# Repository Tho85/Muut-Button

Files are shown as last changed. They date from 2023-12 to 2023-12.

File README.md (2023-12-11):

# Muut Button

A hardware button to control the mute state in video conferencing calls.

Muut Button image

## Overview

The device emulates a USB HID Telephony device with buttons and status LEDs. It can be used to mute/unmute and hang up calls in video conferencing software. The built-in LED (or an optional RGB LED ring) visualizes the current mute/unmute/call state. No additional software or browser extensions required.

Successfully tested with Google Meet in Google Chrome. Firefox does not work because it does not implement the WebHID API. Other video conferencing solutions (MS Teams, Skype, ...) might work as well.

## Features

* Mute/unmute video call on button press
* Also works while video call is in background window
* Shows current mute/unmute state via RGB LED ring or builtin LED
* Correctly shows mute state when muted by other participants
* Optional: Push-to-talk
* Optional: Hold to drop call

## Demo

Muut Button demo

## Requirements

### Hardware

* Development board: [ATtiny85 Micro USB Development Board](https://www.aliexpress.com/item/3256805913780170.html)
* Switch: e.g. [CHERRY MX Brown](https://www.cherrymx.de/cherry-mx/mx-original/mx-brown.html)
* RGB LED ring: [Adafruit NeoPixel Ring - 12x](https://www.adafruit.com/product/1643)
* Case + accessories: [3D printed case](hardware/), see [`hardware/`](hardware/) folder

### Software

* See [`firmware/`](firmware/) folder

## Assembly instructions

* See [`hardware/doc/assembly.md`](hardware/doc/assembly.md)

## License

* Firmware: See [`firmware/LICENSE.md`](firmware/LICENSE.md)
* Hardware: See [`hardware/LICENSE.md`](hardware/LICENSE.md)

## Authors

* [Thomas Hollstegge](https://github.com/Tho85)

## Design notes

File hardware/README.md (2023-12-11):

# Muut Button case
[][cc-by-sa]

## Overview

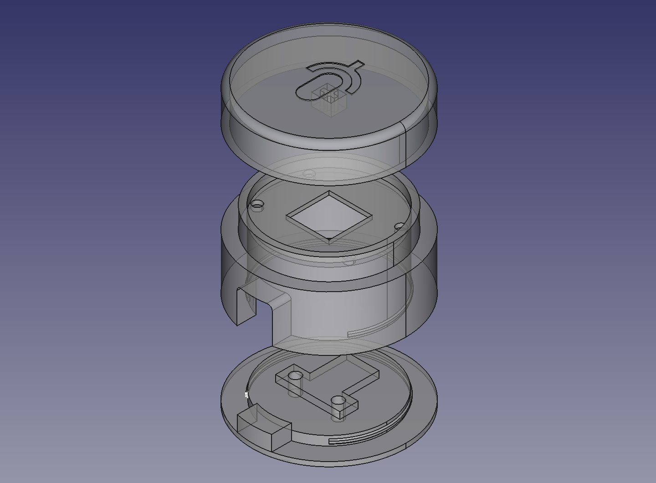
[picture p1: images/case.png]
case image


## Requirements

* Electronics components: See [overall README.md](../README.md)
* A 3D printer and filament
* 2x [M2 threaded inserts](https://turmberg3d.de/products/gewindeeinsatze-fur-kunststoffteile?variant=39376894001347)
* 2x M2x4 screws
* Five short wires (~ 5 cm)
* Some hot glue
* Optional: Foam rubber pad, round

## Assembly instructions

See [doc/assembly.md](doc/assembly.md)

## License

This work is licensed under a
[Creative Commons Attribution-ShareAlike 4.0 International License][cc-by-sa].

[][cc-by-sa]

[cc-by-sa]: http://creativecommons.org/licenses/by-sa/4.0/
[cc-by-sa-image]: https://licensebuttons.net/l/by-sa/4.0/88x31.png
[cc-by-sa-shield]: https://img.shields.io/badge/License-CC%20BY--SA%204.0-lightgrey.svg

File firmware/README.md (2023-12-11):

# Muut Button firmware

A firmware for ATtiny85 microcontrollers that can mute/unmute and hang up calls in video conferencing sofware.

## Features

The firmware emulates the following usages according to the USB HID specification (see [HID Usage Tables](https://usb.org/sites/default/files/hut1_4.pdf)):

| Page name | Page ID | Usage name  | Usage ID |
| --- | --- | --- | --- |
| LED | `0x08`  | Mute | `0x09` |
| LED | `0x08`  | Off-Hook | `0x17` |
| Telephony Device | `0x0B`  | Hook Switch | `0x20` |
| Telephony Device | `0x0B`  | Drop | `0x26` |
| Telephony Device | `0x0B`  | Phone Mute  | `0x2F` |

## Getting Started

### Prerequisites

Hardware:

* Development board: [ATtiny85 Micro USB Development Board](https://www.aliexpress.com/item/3256805913780170.html)
* Or any other ATtiny85 development board where USB communication is handled by the ATtiny85 itself, and not by some additional USB-to-UART controller (CP2102, CH340, etc.)

Software:

* [PlatformIO](https://platform.io)
* [V-USB](https://github.com/obdev/v-usb)

### Installation

* Install [PlatformIO](https://platform.io)
* Clone this repository, `cd firmware/`
* Configure firmware
  * Generate your own config file: `cp include/config.h.example include/config.h`
  * Edit `include/config.h` to suit your needs (see comments there for further description)
* Flash firmware
  * `pio run -t upload`
  * Plug in the device within 60 seconds
* Make sure user has read/write access to the raw USB device:
  * Either drop [`udev rules file`](doc/98-muut.rules) to `/etc/udev/rules.d/`, issue a `sudo udevadm control --reload-rules` and re-plug device (recommended)
  * Or try manually: `sudo chmod 0666 /dev/hidrawX`

### Usage

* Attach device via USB
* Configure video conferencing software to use the device for call controls:
  * [Google Meet](https://support.google.com/meet/answer/12562325?hl=en)

### Advanced usage

If your development board does not already come pre-flashed with it, I highly recommend the [micronucleus bootloader](https://github.com/micronucleus/micronucleus). It adds support for firmware flashing without a dedicated programmer.

By default, the bootloader always starts and waits for up to 6 seconds after plugging in the device before starting the actual firmware. You can improve this behavior by flashing an optimized version of micronucleus as provided in the [`doc/micronucleus`](doc/micronucleus/) folder. The modified configuration only starts into bootloader mode if the button is pressed while plugging in the device.

Please check the [micronucleus repository](https://github.com/micronucleus/micronucleus) for more information on how to flash the optimized bootloader. Hint: micronucleus can update itself via their provided CLI tool.

## License

See [LICENSE.md](LICENSE.md)

## Authors

* [Thomas Hollstegge](https://github.com/Tho85)

## Acknowledgments

* Inspired by [Digispark Keyboard](https://github.com/digistump/DigisparkArduinoIntegration/tree/master/libraries/DigisparkKeyboard)
* Powered by the [micronucleus bootloader](https://github.com/micronucleus/micronucleus)
* Only possible thanks to [V-USB](https://github.com/obdev/v-usb)

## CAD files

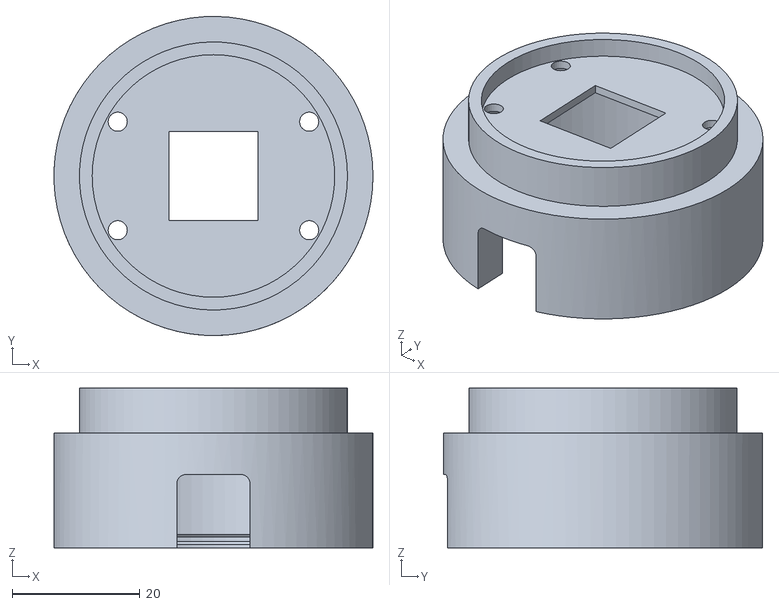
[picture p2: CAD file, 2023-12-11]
hardware/Muut-Stand.stl
50.0 x 50.0 x 25.0

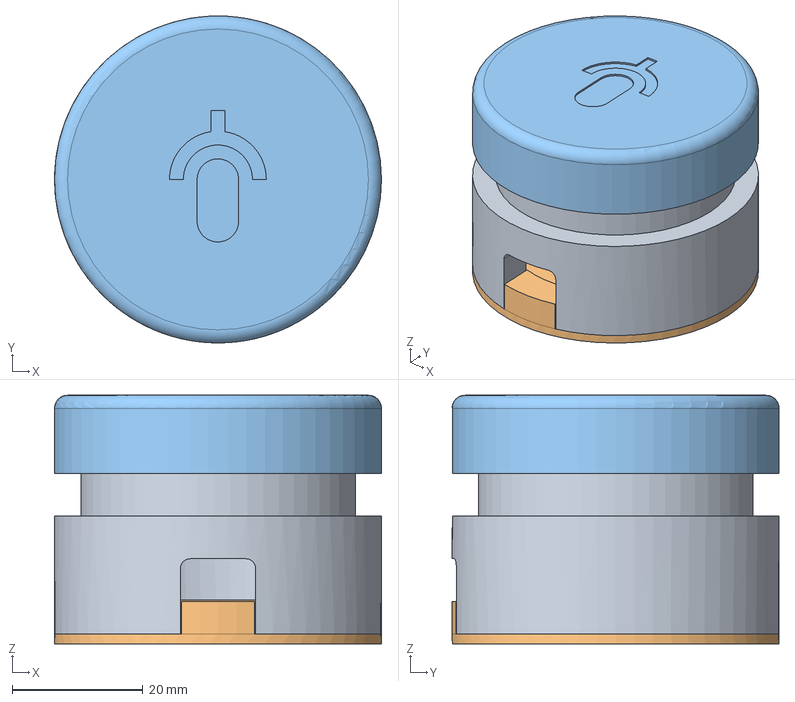
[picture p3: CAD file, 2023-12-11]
hardware/Muut.FCStd
50.0 x 50.0 x 38.0 mm
Stand
Base
Cap

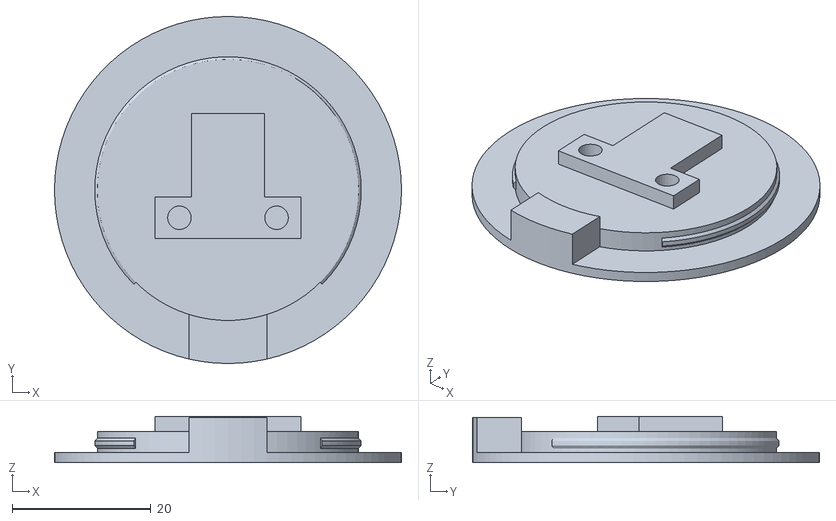
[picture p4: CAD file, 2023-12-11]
hardware/Muut-Base.stl
50.0 x 50.0 x 6.70

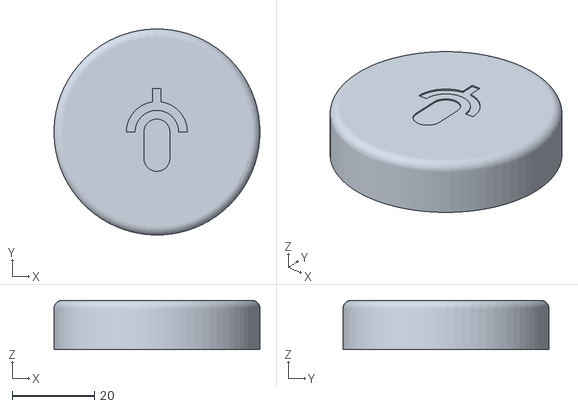
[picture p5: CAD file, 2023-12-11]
hardware/Muut-Cap.stl
50.0 x 50.0 x 12.0

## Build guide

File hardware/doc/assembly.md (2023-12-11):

# Muut Button case and electronics assembly

## Overview

The case consists of three 3D printed parts. From bottom to top:

  * The **base**: This is where the ATtiny85 development board will be mounted
  * The **stand**: This is the middle body which will hold the LED ring and MX switch
  * The **cap**: This is where you press.

## Assembly instructions

### 1. 3D print the case

I did print mine in [white PLA](https://www.dasfilament.de/filament-spulen/pla-1-75-mm/349/pla-filament-1-75-mm-tonweiss-matt?c=11), although any material should do fine.

Printing tips for the **cap**:

* Print the cap **upside down** so that you do not need any support
* Print the cap with **100% infill**, or otherwise the infill pattern might shine through the top when illuminated by the LED ring
* Print at least the middle part with a **reduced speed** so that the connector to the MX switch will be precise

Printing tips for the **stand**:

* Print the stand as it is, with **support** coming in from the bottom. It is more important to have a smooth surface at the top where you will attach the LED ring later.

---

### 2. Prepare and attach NeoPixel LED ring to the stand

* Solder three short wires (~ 5 cm) to the `GND`, `PWR` and `IN` connectors
* Stick the three wires through the small holes in the stand's top
* Fixate the LED ring with some hot glue

---

### 3. Prepare and attach MX switch to the stand

* Solder two short wires (~ 5 cm) to the pins of the switch
* Yes, they are tiny, so don't resign...
* Stick the MX switch through the stand's top

| assembly 2 |
|:--:| 
| *Step 3* |

---

### 4. Solder component wires to the ATtiny85 board

* _After_ putting the components into place, solder the wires to the ATtiny85 board

  | Component | Component pin | ATtiny85 board pin  |
  | --------- | ------------- | ------------------- |
  | LED ring  | `GND`         | `GND` *)            |
  | LED ring  | `PWR`         | `VIN` (**not** 5V!) |
  | LED ring  | `IN`          | `PB0`               |
  | MX switch | Pin 1         | `GND` *)            |
  | MX switch | Pin 2         | `PB2`               |

  *) Two wires need to be soldered into the single `GND` hole. If you did not read this before doing so, you might also think about soldering the MX switch pin to a different `PBx` pin and pulling that one to `GND` in software. You might want to try though which of the pins actually works and doesn't interfer with the USB communication.

---

### 5. Prepare and attach ATtiny85 development board to the base

* Melt down the two threaded inserts into the base
* Attach the ATtiny85 development board with two M2x4 screws

| assembly 1 |
|:--:| 
| *Step 5* |

---

### 6. Snap-fit everything together

* Click the base into place
* Attach the cap to the switch. Please bear in mind that the cap can only be mounted in two directions (the connector will only rotate by 180° and not by 90°). Choose the orientation according to your taste.
* Attach Micro USB cable through the connector hole

---

### 7. Optional: Foam rubber pad

* Cut out a round shape of thin foam rubber
* Attach with some strong double-faced adhesive tape to the bottom of the base

---

### 8. Done!

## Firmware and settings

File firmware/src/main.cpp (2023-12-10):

#include "main.h"

Adafruit_NeoPixel leds(NUM_LEDS, RGB_LED_PIN, NEO_GRB + NEO_KHZ800);
Bounce2::Button muteButton = Bounce2::Button();

#ifdef ENABLE_PUSH_TO_TALK
bool pttActive = false;
bool lastPttActive = false;
#endif

bool lastRemoteMuteState = false;
bool remoteMuteState = false;

bool lastRemoteCallState = false;
bool remoteCallState = false;

const PROGMEM uint32_t colorBlack = 0x000000;
const PROGMEM uint32_t colorRed = 0xFF0000;
const PROGMEM uint32_t colorGreen = 0x00FF00;
uint32_t currentColor = colorBlack;

#ifdef ENABLE_HOLD_TO_DROP
bool holdToDrop = false;
#endif

#if defined(ENABLE_IDLE_RAINBOW) || defined(ENABLE_UNMUTED_RAINBOW)
bool enableRainbow = false;
#endif

void setup() {
#ifdef ENABLE_BUILTIN_LED
  pinMode(BUILTIN_LED_PIN, OUTPUT);
  digitalWrite(BUILTIN_LED_PIN, LOW);
#endif

  muteButton.attach(MUTE_BUTTON_PIN, INPUT_PULLUP);
  digitalWrite(MUTE_BUTTON_PIN, HIGH);
  muteButton.interval(20);
  muteButton.setPressedState(LOW);

#if defined(ENABLE_IDLE_RAINBOW) || defined(ENABLE_UNMUTED_RAINBOW)
  enableRainbow = muteButton.read() == LOW;
#endif

  leds.begin();
  leds.clear();
  leds.show();
  leds.setBrightness(RGB_LED_BRIGHTNESS);
}

void toggleMuteState() {
  UsbMute.setMute(!remoteMuteState);
}

void displayRainbow() {
  uint16_t hue = ((millis() * 65535) / RAINBOW_DURATION) % 65535;
  for (int i = 0; i < NUM_LEDS; ++i) {
    leds.setPixelColor(i, leds.ColorHSV(hue + (i * 65535) / NUM_LEDS, 255, 200));
  }
}
void loop() {
  lastRemoteCallState = remoteCallState;
  remoteCallState = UsbMute.getMuteLED();

  lastRemoteMuteState = remoteMuteState;
  remoteMuteState = UsbMute.getOffHookLED();

#ifdef ENABLE_BUILTIN_LED
  digitalWrite(BUILTIN_LED_PIN, remoteMuteState ? HIGH : LOW);
#endif

  if (remoteCallState != lastRemoteCallState || remoteMuteState != lastRemoteMuteState) {
    leds.setBrightness(RGB_LED_BRIGHTNESS);
    if (remoteCallState)
      currentColor = remoteMuteState ? colorRed : colorGreen;
    else
      currentColor = colorBlack;

    leds.fill(currentColor);
  }

#ifdef ENABLE_UNMUTED_RAINBOW
  if (enableRainbow && remoteCallState && !remoteMuteState)
    displayRainbow();
#endif

  muteButton.update();

#ifdef ENABLE_HOLD_TO_DROP
  if (muteButton.released()) {
#else
  if (muteButton.pressed()) {
#endif
    toggleMuteState();
  }

#ifdef ENABLE_HOLD_TO_DROP
  if (muteButton.read() == LOW) {
    unsigned long currentDuration = muteButton.currentDuration();
    int brightness = 255 - ((currentDuration * 255) / HOLD_TO_DROP_DURATION);
    leds.setBrightness(max(min(brightness, 255), 0) * RGB_LED_BRIGHTNESS / 255);

    if (currentDuration > HOLD_TO_DROP_DURATION) {
      holdToDrop = true;
      UsbMute.setDrop(true);
    }
  }

  if (muteButton.released() && holdToDrop) {
    UsbMute.setDrop(false);
    holdToDrop = false;
  }
#endif

#ifdef ENABLE_PUSH_TO_TALK
  if (muteButton.released() && pttActive)
    toggleMuteState();

  pttActive = muteButton.read() == LOW && muteButton.currentDuration() > PTT_TRIGGER_DURATION;

  if (pttActive) {
#ifdef PTT_EFFECT_ROTATING_LIGHT
    leds.clear();
    int idx = (millis() / (PTT_EFFECT_ROTATING_LIGHT_DURATION / NUM_LEDS)) % NUM_LEDS;
    for (int i = idx; i < idx + NUM_LEDS / 4; i++) {
      leds.setPixelColor(i % NUM_LEDS, currentColor);
      leds.setPixelColor((i + NUM_LEDS/2) % NUM_LEDS, currentColor);
    }
#endif

#ifdef PTT_EFFECT_PULSE
    int brightnessTwo = ((muteButton.currentDuration() * 512) / PTT_EFFECT_PULSE_DURATION) % 512;
    int brightness = (min(brightnessTwo, 511 - brightnessTwo) * RGB_LED_BRIGHTNESS) / 255;
    // There is a calculation error in the two lines above, leading to a visible
    // black flash, because brightness is obviously > 255. Manually limit to
    // interval between 0 and 255.
    leds.setBrightness(max(min(brightness, 255), 1));
#endif
  }

  lastPttActive = pttActive;
#endif

#ifdef ENABLE_IDLE_RAINBOW
  if (enableRainbow && !remoteCallState)
    displayRainbow();
#endif

  leds.show();
  UsbMute.delay(20);
}

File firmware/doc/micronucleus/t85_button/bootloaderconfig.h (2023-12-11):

/* Name: bootloaderconfig.h
 * Micronucleus configuration file.
 * This file (together with some settings in Makefile.inc) configures the boot loader
 * according to the hardware.
 *
 * Controller type: ATtiny 85 - 16.5 MHz
 * Configuration:   Default configuration
 *       USB D- :   PB3
 *       USB D+ :   PB4
 *       Entry  :   Button (PB2)
 *       LED    :   None
 *       OSCCAL :   Stays at 16 MHz
 * Note: Uses 16.5 MHz V-USB implementation with PLL
 *
 * License: GNU GPL v2 (see License.txt
 */
#ifndef __bootloaderconfig_h_included__
#define __bootloaderconfig_h_included__

/* ------------------------------------------------------------------------- */
/*                       Hardware configuration.                             */
/*      Change this according to your CPU and USB configuration              */
/* ------------------------------------------------------------------------- */

#define USB_CFG_IOPORTNAME      B
  /* This is the port where the USB bus is connected. When you configure it to
   * "B", the registers PORTB, PINB and DDRB will be used.
   */

#define USB_CFG_DMINUS_BIT      3
/* This is the bit number in USB_CFG_IOPORT where the USB D- line is connected.
 * This may be any bit in the port.
 * USB- has a 1.5k pullup resistor to indicate a low-speed device.
 */
#define USB_CFG_DPLUS_BIT       4
/* This is the bit number in USB_CFG_IOPORT where the USB D+ line is connected.
 * This may be any bit in the port, but must be configured as a pin change interrupt.
 */

#define USB_CFG_CLOCK_KHZ       (F_CPU/1000)
/* Clock rate of the AVR in kHz. Legal values are 12000, 12800, 15000, 16000,
 * 16500, 18000 and 20000. The 12.8 MHz and 16.5 MHz versions of the code
 * require no crystal, they tolerate +/- 1% deviation from the nominal
 * frequency. All other rates require a precision of 2000 ppm and thus a
 * crystal!
 * Since F_CPU should be defined to your actual clock rate anyway, you should
 * not need to modify this setting.
 */

/* ----------------------- Optional Hardware Config ------------------------ */
//#define USB_CFG_PULLUP_IOPORTNAME   B
/* If you connect the 1.5k pullup resistor from D- to a port pin instead of
 * V+, you can connect and disconnect the device from firmware by calling
 * the macros usbDeviceConnect() and usbDeviceDisconnect() (see usbdrv.h).
 * This constant defines the port on which the pullup resistor is connected.
 */
//#define USB_CFG_PULLUP_BIT          0
/* This constant defines the bit number in USB_CFG_PULLUP_IOPORT (defined
 * above) where the 1.5k pullup resistor is connected. See description
 * above for details.
 */

/* ------------- Set up interrupt configuration (CPU specific) --------------   */
/* The register names change quite a bit in the ATtiny family. Pay attention    */
/* to the manual. Note that the interrupt flag system is still used even though */
/* interrupts are disabled. So this has to be configured correctly.             */

// setup interrupt for Pin Change for D+
#define USB_INTR_CFG            PCMSK // Pin interrupt enable register
#define USB_INTR_CFG_SET        (1 << USB_CFG_DPLUS_BIT) // Mask for pin in pin interrupt enable register PCMSK to be set on usbInit
#define USB_INTR_CFG_CLR        0 // Mask for pin in pin interrupt enable register PCMSK to be cleared on usbInit. 0 = no clear
#define USB_INTR_ENABLE         GIMSK // Global interrupt enable register
#define USB_INTR_ENABLE_BIT     PCIE  // Bit position in global interrupt enable register
#define USB_INTR_PENDING        GIFR  // Register to read interrupt flag
#define USB_INTR_PENDING_BIT    PCIF  // Bit position in register to read interrupt flag

// Theoretical this should work, but I get "Starting to upload ... >> Flash write error: Input/output error has occured" when a application is still loaded
//#define USB_INTR_CFG            MCUCR // requires 4 bit extra code size since sbi is not possible for MCUCR
//#define USB_INTR_CFG_SET        (1 << ISC00)
//#define USB_INTR_CFG_CLR        0
//#define USB_INTR_ENABLE         GIMSK
//#define USB_INTR_ENABLE_BIT     INT0
//#define USB_INTR_PENDING        GIFR
//#define USB_INTR_PENDING_BIT    INTF0

/* ------------------------------------------------------------------------- */
/*       Configuration relevant to the CPU the bootloader is running on      */
/* ------------------------------------------------------------------------- */

// how many milliseconds should host wait till it sends another erase or write?
// needs to be above 4.5 (and a whole integer) as avr freezes maximum for 4.5ms
// while writing a FLASH page (even for 128 byte page size:-))
#define MICRONUCLEUS_WRITE_SLEEP 5


/* ---------------------- feature / code size options ---------------------- */
/*               Configure the behavior of the bootloader here               */
/* ------------------------------------------------------------------------- */
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

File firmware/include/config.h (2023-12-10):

#ifndef __config_h__
#define __config_h__

/*
 * Number of LEDs on your NeoPixel Ring
 */
#define NUM_LEDS 12

/*
 * RGB LED brightness (0 = off, 255 = maximum brightness)
 */
#define RGB_LED_BRIGHTNESS 70

/*
 * Pin definition
 *
 * NeoPixel Ring only seems to work on PB0
 */
#define RGB_LED_PIN PB0
#define BUILTIN_LED_PIN PB1
#define MUTE_BUTTON_PIN PB2

/*
 * Signal mute state by using internal LED of Digispark board
 */
//#define ENABLE_BUILTIN_LED

/*
 * Push to talk (PTT)
 *
 * When enabled, pushing and holding the button for longer than
 * PTT_TRIGGER_DURATION milliseconds will switch to push-to-talk mode
 * temporarily. When releasing the button again, the mute state will return to
 * its previous state.
 */
//#define ENABLE_PUSH_TO_TALK
#define PTT_TRIGGER_DURATION 1000

/*
 * Signal active PTT by showing a rotating red or green light (depending on
 * mute state)
 */
//#define PTT_EFFECT_ROTATING_LIGHT
#define PTT_EFFECT_ROTATING_LIGHT_DURATION 1000

/*
 * Signal active PTT by showing a pulsing red or green light (depending on
 * mute state)
 */
//#define PTT_EFFECT_PULSE
#define PTT_EFFECT_PULSE_DURATION 1000

/*
 * Hold to drop
 *
 * When enabled, pushing and holding the button for longer than
 * HOLD_TO_DROP_DURATION milliseconds will hang up the active call. This is
 * signalled by a fading red or green light (depending on mute state) until the
 * call is dropped.
 */
#define ENABLE_HOLD_TO_DROP
#define HOLD_TO_DROP_DURATION 1000

/*
 * Easter egg: Use rainbow instead of green light when unmuted.
 *
 * To activate: Hold down button when plugging in USB cable, and wait until the
 * bootloader has finished (~ 7-8 seconds)
 */
#define ENABLE_UNMUTED_RAINBOW
#define RAINBOW_DURATION 5000

/*
 * Easter egg: Use rainbow in idle state
 *
 * To activate: Hold down button when plugging in USB cable, and wait until the
 * bootloader has finished (~ 7-8 seconds)
 */
//#define ENABLE_IDLE_RAINBOW

#endif // __config_h__

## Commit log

2023-12-10 Provide a more realistic power consumption estimate
2023-12-11 Add case files
    [Muut-Base.stl, Muut-Cap.stl, Muut-Stand.stl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]
2023-12-11 Add assembly instructions
    [Muut-Base.stl, Muut-Cap.stl, Muut-Stand.stl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]
2023-12-11 Add assembly images
2023-12-11 Add link to assembly instructions to README

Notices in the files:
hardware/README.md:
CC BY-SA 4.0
